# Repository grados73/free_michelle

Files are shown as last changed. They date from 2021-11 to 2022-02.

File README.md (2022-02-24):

# Aquarium controller
>The project, with the working name "free_miechelle", is a response to the lack of market proposals for aquarium control and management devices.

>>Now this project is being developed in another repository. -> https://github.com/grados73/akwa_elektron

## Table of contents
* [General info](#general-info)
* [Screenshots](#screenshots)
* [Technologies](#technologies)
* [HARDWARE](#hardware)
* [Features](#features)
* [Status](#status)
* [Inspiration](#inspiration)
* [Contact](#contact)

## General info
Aquarium hobby has been one of my hobbies for over 10 years, along with cars, sports and electronics. I am a bit of a gadgeteer and like to have everything possible in a smart version, with easy management and monitoring. The same goes for aquariums, I would like to enjoy all the benefits that come with this hobby. Yes, I am a bit lazy. I would like to put in as little effort as possible, while being sure that my fish are well taken care of, even when I am away from home.  But there are no satisfactory solutions on the market to buy and use. All the devices that already exist have either limited capabilities or a technological debt that is heavily visible. Therefore, I decided to make such a device myself. I am currently at the stage of the first prototype, which I assemble using prototype boards. 

## Screenshots
Currently, the device is in a prototype version. It has been assembled on two prototype boards. The next version will have a dedicated PCB.
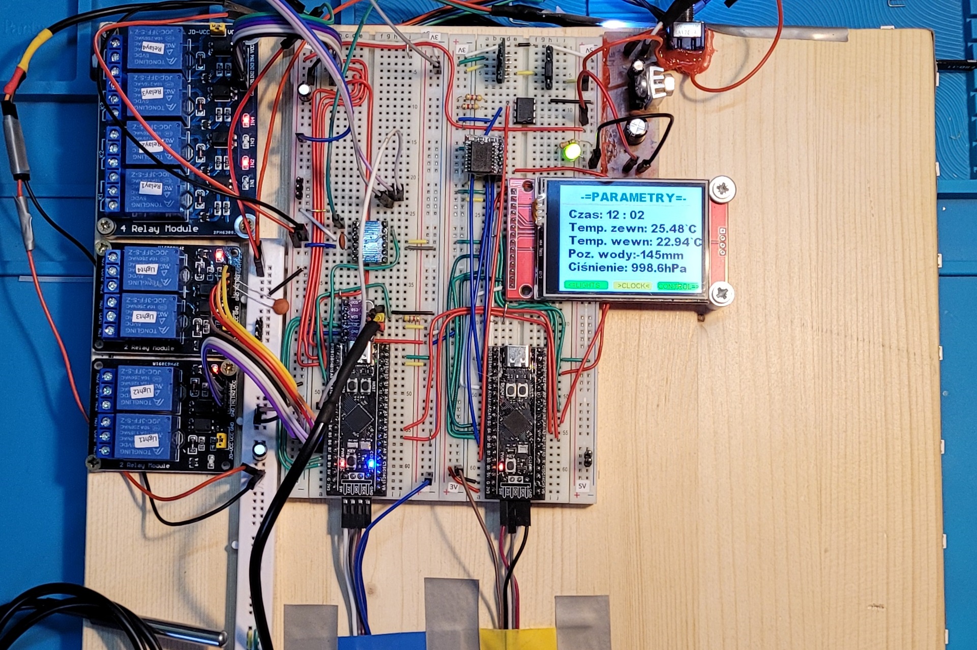
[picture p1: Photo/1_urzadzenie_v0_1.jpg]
Device photo


Short wideo:
https://youtu.be/HiZ6xpy-laI

Currently, the software allows you to control the device and communicate with it through a 2.4" TFT screen, controlled by SPI. All commands are issued via the touch screen available on each of the 8 menu screens. 
Screen photo

## Technologies
Project is created with:
* C,
* HAL for STM32F4,
*
* STM32CubeIDE,
* The Dot Factory v.0.1.4,
* InkScape v.0.92.4,
* Image2Lcd v3.2

## HARDWARE
* 2x Blackpill STM32F411CEU6 
* TFT LCD 2,4″ (240x320px) with ILI9341 controller - SPI
* RTC DS3231 - I2C
* EEPROM memory 1kb - I2C
* BMP280 - I2C
* DS18B20 - 1-WIRE
* Ultrasonic distance sensor - DFRobot SEN0311 - UART
* WS2812b - I2C

## Features
* Menu on TFT Display - DONE
* Touch Interface - DONE
* Relay Control - DONE
* WS2812b LEDs Control  - DONE
* Predefined Activities like feeding or cleaning - DONE
* Display Pressure and Temperature inside and outside the aquarium  - DONE
* Display current day of week, hour and minute and possibility to change them in RTC - DONE
* Measuring the water level in the aquarium - DONE

## To-do list
* Shedules - TODO
* Alarms - TODO
* PCB - TODO
* Watchdog - TODO
* UPS - TODO
* Online access(ESP) - TODO
* Wireless comunitation with sensors - nRF24L01+ - TODO
* Push inormation on telephone - TODO

## Status
Project is in progress and i will develop them to learn ARM and STM32.

## Inspiration
It will be added.

## Contact
Created by https://www.linkedin.com/in/kamil-gradowski-8706991aa - feel free to contact me!
grados73

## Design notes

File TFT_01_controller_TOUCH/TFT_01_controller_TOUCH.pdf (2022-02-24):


12/01/2022

## TFT_01_controller_TOUCH Project Configuration Report

# 1. Description

## 1.1. Project

Project Name | TFT_01_controller_TOUCH
Board Name | custom
Generated with: | STM32CubeMX 6.4.0
Date | 01/12/2022

## 1.2. MCU

MCU Series | STM32F4
MCU Line | STM32F411
MCU name | STM32F411CEUx
MCU Package | UFQFPN48
MCU Pin number | 48

## 1.3. Core(s) information

Core(s) | Arm Cortex-M4

# 2. Pinout Configuration

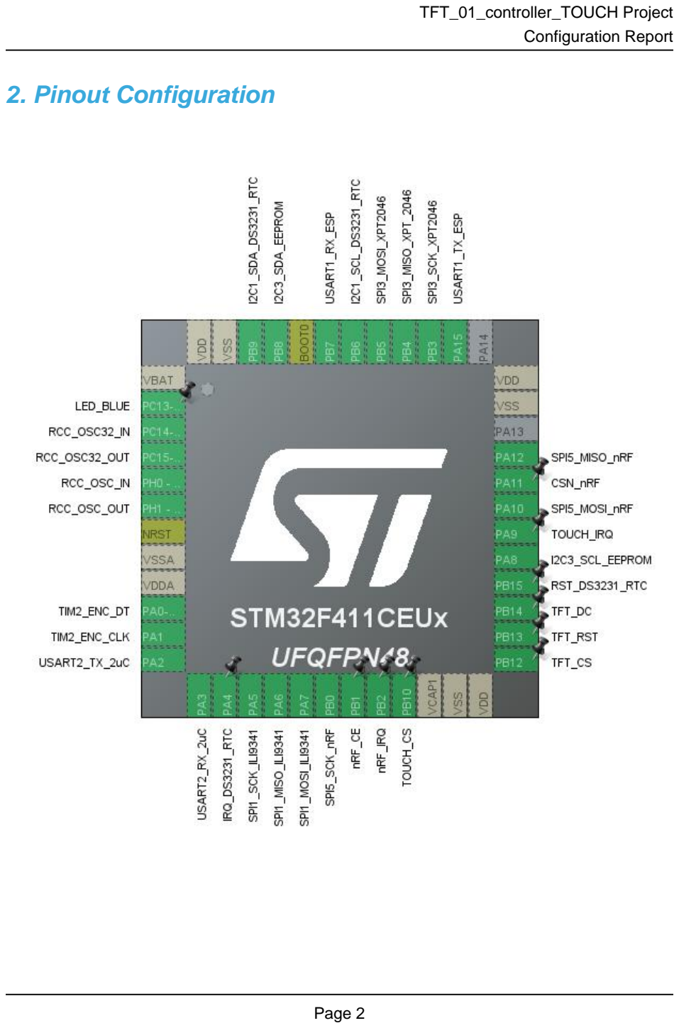
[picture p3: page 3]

# 3. Pins Configuration

Pin Number UFQFPN48 | Pin Name (function after reset) | Pin Type | Alternate Function(s) | Label
1 | VBAT | Power
2 | PC13-ANTI_TAMP * | I/O | GPIO_Output | LED_BLUE
3 | PC14-OSC32_IN | I/O | RCC_OSC32_IN
4 | PC15-OSC32_OUT | I/O | RCC_OSC32_OUT
5 | PH0 - OSC_IN | I/O | RCC_OSC_IN
6 | PH1 - OSC_OUT | I/O | RCC_OSC_OUT
7 | NRST | Reset
8 | VSSA | Power
9 | VDDA | Power
10 | PA0-WKUP | I/O | TIM2_CH1 | TIM2_ENC_DT
11 | PA1 | I/O | TIM2_CH2 | TIM2_ENC_CLK
12 | PA2 | I/O | USART2_TX | USART2_TX_2uC
13 | PA3 | I/O | USART2_RX | USART2_RX_2uC
14 | PA4 | I/O | GPIO_EXTI4 | IRQ_DS3231_RTC
15 | PA5 | I/O | SPI1_SCK | SPI1_SCK_ILI9341
16 | PA6 | I/O | SPI1_MISO | SPI1_MISO_ILI9341
17 | PA7 | I/O | SPI1_MOSI | SPI1_MOSI_ILI9341
18 | PB0 | I/O | SPI5_SCK | SPI5_SCK_nRF
19 | PB1 * | I/O | GPIO_Output | nRF_CE
20 | PB2 | I/O | GPIO_EXTI2 | nRF_IRQ
21 | PB10 * | I/O | GPIO_Output | TOUCH_CS
22 | VCAP1 | Power
23 | VSS | Power
24 | VDD | Power
25 | PB12 * | I/O | GPIO_Output | TFT_CS
26 | PB13 * | I/O | GPIO_Output | TFT_RST
27 | PB14 * | I/O | GPIO_Output | TFT_DC
28 | PB15 * | I/O | GPIO_Input | RST_DS3231_RTC
29 | PA8 | I/O | I2C3_SCL | I2C3_SCL_EEPROM
30 | PA9 | I/O | GPIO_EXTI9 | TOUCH_IRQ
31 | PA10 | I/O | SPI5_MOSI | SPI5_MOSI_nRF
32 | PA11 * | I/O | GPIO_Output | CSN_nRF
33 | PA12 | I/O | SPI5_MISO | SPI5_MISO_nRF
35 | VSS | Power
36 | VDD | Power
38 | PA15 | I/O | USART1_TX | USART1_TX_ESP

Pin Number UFQFPN48 | Pin Name (function after reset) | Pin Type | Alternate Function(s) | Label
39 | PB3 | I/O | SPI3_SCK | SPI3_SCK_XPT2046
40 | PB4 | I/O | SPI3_MISO | SPI3_MISO_XPT_2046
41 | PB5 | I/O | SPI3_MOSI | SPI3_MOSI_XPT2046
42 | PB6 | I/O | I2C1_SCL | I2C1_SCL_DS3231_RTC
43 | PB7 | I/O | USART1_RX | USART1_RX_ESP
44 | BOOT0 | Boot
45 | PB8 | I/O | I2C3_SDA | I2C3_SDA_EEPROM
46 | PB9 | I/O | I2C1_SDA | I2C1_SDA_DS3231_RTC
47 | VSS | Power
48 | VDD | Power

## * The pin is affected with an I/O function

# 4. Clock Tree Configuration

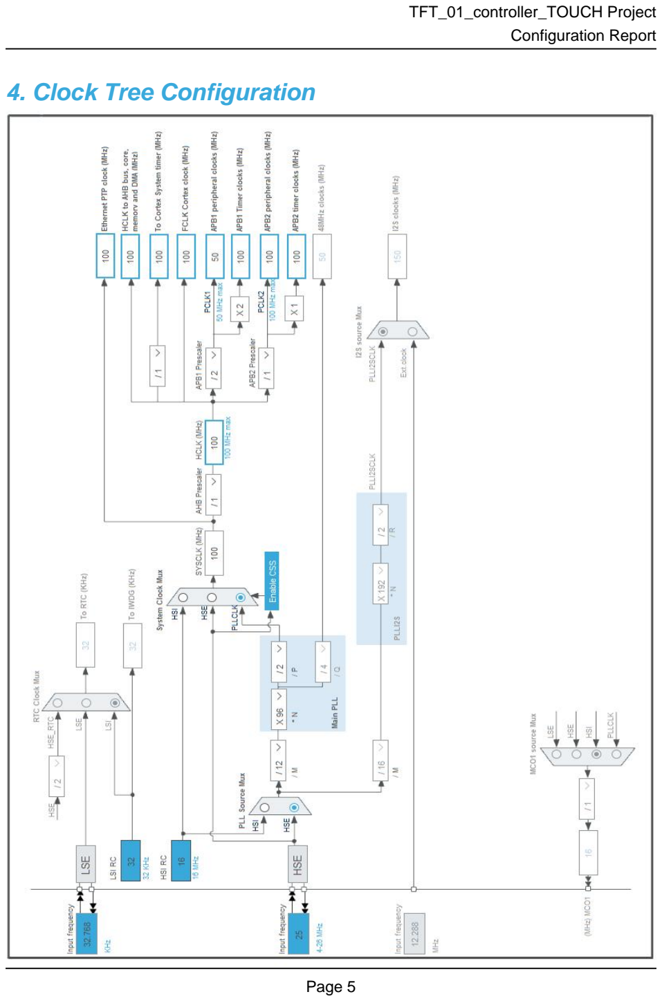
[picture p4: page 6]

# 5. Software Project

## 5.1. Project Settings

Name | Value
Project Name | TFT_01_controller_TOUCH
Project Folder | D:\STM32\free_michelle\TFT_01_controller_TOUCH
Toolchain / IDE | STM32CubeIDE
Firmware Package Name and Version | STM32Cube FW_F4 V1.26.2
Application Structure | Advanced
Generate Under Root | Yes
Do not generate the main() | No
Minimum Heap Size | 0x200
Minimum Stack Size | 0x400

## 5.2. Code Generation Settings

Name | Value
STM32Cube MCU packages and embedded software | Copy only the necessary library files
Generate peripheral initialization as a pair of '.c/.h' files | Yes
Backup previously generated files when re-generating | No
Keep User Code when re-generating | Yes
Delete previously generated files when not re-generated | Yes
Set all free pins as analog (to optimize the power consumption) | No
Enable Full Assert | No

## 5.3. Advanced Settings - Generated Function Calls

Rank | Function Name | Peripheral Instance Name
1 | MX_GPIO_Init | GPIO
2 | SystemClock_Config | RCC
3 | MX_SPI1_Init | SPI1
4 | MX_DMA_Init | DMA
5 | MX_USART2_UART_Init | USART2
6 | MX_SPI3_Init | SPI3
7 | MX_I2C1_Init | I2C1
8 | MX_TIM11_Init | TIM11
9 | MX_TIM10_Init | TIM10
10 | MX_I2C3_Init | I2C3
11 | MX_SPI5_Init | SPI5

Rank | Function Name | Peripheral Instance Name
12 | MX_USART1_UART_Init | USART1
13 | MX_TIM2_Init | TIM2

# 6. Power Consumption Calculator report

## 6.1. Microcontroller Selection

Series | STM32F4
Line | STM32F411
MCU | STM32F411CEUx
Datasheet | DS10314_Rev6

## 6.2. Parameter Selection

Temperature | 25
Vdd | 1.7

## 6.3. Battery Selection

Battery | Li-SOCL2(A3400)
Capacity | 3400.0 mAh
Self Discharge | 0.08 %/month
Nominal Voltage | 3.6 V
Max Cont Current | 100.0 mA
Max Pulse Current | 200.0 mA
Cells in series | 1
Cells in parallel | 1

## 6.4. Sequence

Step | Step1 | Step2
Mode | RUN | STOP
Vdd | 1.7 | 1.7
Voltage Source | Battery | Battery
Range | Scale1-High | No Scale
Fetch Type | SRAM | n/a
CPU Frequency | 100 MHz | 0 Hz
Clock Configuration | HSE PLL | Regulator_LPLV Flash-PwrDwn
Clock Source Frequency | 4 MHz | 0 Hz

### Peripherals

Additional Cons. | 0 mA | 0 mA
Average Current | 12.7 mA | 9 µA
Duration | 0.1 ms | 0.9 ms
DMIPS | 125.0 | 0.0
Ta Max | 104.31 | 105
Category | In DS Table | In DS Table

## 6.5. Results

Sequence Time | 1 ms | Average Current | 1.28 mA
Battery Life | 3 months, 19 days, 6 hours | Average DMIPS | 125.0 DMIPS

## 6.6. Chart

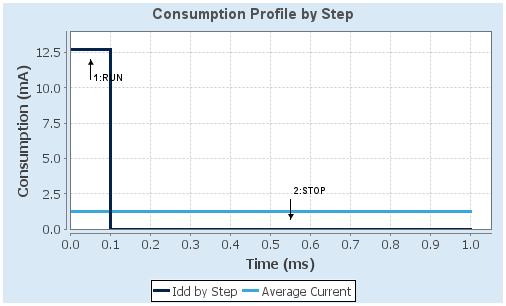
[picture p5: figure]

# 7. Peripherals and Middlewares Configuration

## 7.1. I2C1 I2C: I2C

## 7.1.1. Parameter Settings:

### Master Features:

I2C Speed Mode | Fast Mode *
I2C Clock Speed (Hz) | 400000
Fast Mode Duty Cycle | Duty cycle Tlow/Thigh = 2

### Slave Features:

Clock No Stretch Mode | Disabled
Primary Address Length selection | 7-bit
Dual Address Acknowledged | Disabled
Primary slave address | 0
General Call address detection | Disabled

## 7.2. I2C3 I2C: I2C

## 7.2.1. Parameter Settings:

### Master Features:

I2C Speed Mode | Standard Mode
I2C Clock Speed (Hz) | 100000

### Slave Features:

Clock No Stretch Mode | Disabled
Primary Address Length selection | 7-bit
Dual Address Acknowledged | Disabled
Primary slave address | 0
General Call address detection | Disabled

## 7.3. RCC High Speed Clock (HSE): Crystal/Ceramic Resonator Low Speed Clock (LSE) : Crystal/Ceramic Resonator

## 7.3.1. Parameter Settings:

### System Parameters:

VDD voltage (V) | 3.3
Instruction Cache | Enabled
Prefetch Buffer | Enabled
Data Cache | Enabled
Flash Latency(WS) | 3 WS (4 CPU cycle)

### RCC Parameters:

HSI Calibration Value | 16
TIM Prescaler Selection | Disabled
HSE Startup Timout Value (ms) | 100
LSE Startup Timout Value (ms) | 5000

### Power Parameters:

Power Regulator Voltage Scale | Power Regulator Voltage Scale 1

## 7.4. SPI1 Mode: Full-Duplex Master

## 7.4.1. Parameter Settings:

### Basic Parameters:

Frame Format | Motorola
Data Size | 8 Bits
First Bit | MSB First

### Clock Parameters:

Prescaler (for Baud Rate) | 8 *
Baud Rate | 12.5 MBits/s *
Clock Polarity (CPOL) | Low
Clock Phase (CPHA) | 1 Edge

### Advanced Parameters:

CRC Calculation | Disabled
NSS Signal Type | Software

## 7.5. SPI3 Mode: Full-Duplex Master

## 7.5.1. Parameter Settings:

### Basic Parameters:

Frame Format | Motorola
Data Size | 8 Bits

First Bit | MSB First

### Clock Parameters:

Prescaler (for Baud Rate) | 32 *
Baud Rate | 1.5625 MBits/s *
Clock Polarity (CPOL) | Low
Clock Phase (CPHA) | 1 Edge

### Advanced Parameters:

CRC Calculation | Disabled
NSS Signal Type | Software

## 7.6. SPI5 Mode: Full-Duplex Master

## 7.6.1. Parameter Settings:

### Basic Parameters:

Frame Format | Motorola
Data Size | 8 Bits
First Bit | MSB First

### Clock Parameters:

Prescaler (for Baud Rate) | 2
Baud Rate | 50.0 MBits/s *
Clock Polarity (CPOL) | Low
Clock Phase (CPHA) | 1 Edge

### Advanced Parameters:

CRC Calculation | Disabled
NSS Signal Type | Software

## 7.7. SYS Timebase Source: SysTick

## 7.8. TIM2 Combined Channels: Encoder Mode

## 7.8.1. Parameter Settings:

### Counter Settings:

Prescaler (PSC - 16 bits value) | 0

Counter Mode | Up
Counter Period (AutoReload Register - 32 bits value ) | 4294967295
Internal Clock Division (CKD) | No Division
auto-reload preload | Disable

### Trigger Output (TRGO) Parameters:

Master/Slave Mode (MSM bit) | Disable (Trigger input effect not delayed)
Trigger Event Selection | Reset (UG bit from TIMx_EGR)

### Encoder:

Encoder Mode | Encoder Mode TI1
____ Parameters for Channel 1 ____
Polarity | Rising Edge
IC Selection | Direct
Prescaler Division Ratio | No division
Input Filter | 0
____ Parameters for Channel 2 ____
Polarity | Rising Edge
IC Selection | Direct
Prescaler Division Ratio | No division
Input Filter | 0

## 7.9. TIM10 mode: Activated

## 7.9.1. Parameter Settings:

### Counter Settings:

Prescaler (PSC - 16 bits value) | 9999 *
Counter Mode | Up
Counter Period (AutoReload Register - 16 bits value ) | 9999 *
Internal Clock Division (CKD) | No Division
auto-reload preload | Disable

## 7.10. TIM11 mode: Activated

## 7.10.1. Parameter Settings:

### Counter Settings:

Prescaler (PSC - 16 bits value) | 14999 *

Counter Mode | Up
Counter Period (AutoReload Register - 16 bits value ) | 29999 *
Internal Clock Division (CKD) | Division by 4 *
auto-reload preload | Disable

## 7.11. USART1 Mode: Asynchronous

## 7.11.1. Parameter Settings:

### Basic Parameters:

Baud Rate | 115200
Word Length | 8 Bits (including Parity)
Parity | None
Stop Bits | 1

### Advanced Parameters:

Data Direction | Receive and Transmit
Over Sampling | 16 Samples

## 7.12. USART2 Mode: Asynchronous

## 7.12.1. Parameter Settings:

### Basic Parameters:

Baud Rate | 115200
Word Length | 8 Bits (including Parity)
Parity | None
Stop Bits | 1

### Advanced Parameters:

Data Direction | Receive and Transmit
Over Sampling | 16 Samples

### * User modified value

# 8. System Configuration

## 8.1. GPIO configuration

IP | Pin | Signal | GPIO mode | GPIO pull/up pull down | Max Speed | User Label
I2C1 | PB6 | I2C1_SCL | Alternate Function Open Drain | No pull-up and no pull-down | Very High * | I2C1_SCL_DS3231_RTC
| PB9 | I2C1_SDA | Alternate Function Open Drain | No pull-up and no pull-down | Very High * | I2C1_SDA_DS3231_RTC
I2C3 | PA8 | I2C3_SCL | Alternate Function Open Drain | No pull-up and no pull-down | Very High * | I2C3_SCL_EEPROM
| PB8 | I2C3_SDA | Alternate Function Open Drain | No pull-up and no pull-down | Very High * | I2C3_SDA_EEPROM
RCC | PC14-OSC32_IN | RCC_OSC32_IN | n/a | n/a | n/a
| PC15-OSC32_OU T | RCC_OSC32_O UT | n/a | n/a | n/a
| PH0 -OSC_IN | RCC_OSC_IN | n/a | n/a | n/a
| PH1 -OSC_OUT | RCC_OSC_OUT | n/a | n/a | n/a
SPI1 | PA5 | SPI1_SCK | Alternate Function Push Pull | No pull-up and no pull-down | Very High * | SPI1_SCK_ILI9341
| PA6 | SPI1_MISO | Alternate Function Push Pull | No pull-up and no pull-down | Very High * | SPI1_MISO_ILI9341
| PA7 | SPI1_MOSI | Alternate Function Push Pull | No pull-up and no pull-down | Very High * | SPI1_MOSI_ILI9341
SPI3 | PB3 | SPI3_SCK | Alternate Function Push Pull | No pull-up and no pull-down | Very High * | SPI3_SCK_XPT2046
| PB4 | SPI3_MISO | Alternate Function Push Pull | No pull-up and no pull-down | Very High * | SPI3_MISO_XPT_2046
| PB5 | SPI3_MOSI | Alternate Function Push Pull | No pull-up and no pull-down | Very High * | SPI3_MOSI_XPT2046
SPI5 | PB0 | SPI5_SCK | Alternate Function Push Pull | No pull-up and no pull-down | Very High * | SPI5_SCK_nRF
| PA10 | SPI5_MOSI | Alternate Function Push Pull | No pull-up and no pull-down | Very High * | SPI5_MOSI_nRF
| PA12 | SPI5_MISO | Alternate Function Push Pull | No pull-up and no pull-down | Very High * | SPI5_MISO_nRF

IP | Pin | Signal | GPIO mode | GPIO pull/up pull down | Max Speed | User Label
TIM2 | PA0-WKUP | TIM2_CH1 | Alternate Function Push Pull | No pull-up and no pull-down | Low | TIM2_ENC_DT
| PA1 | TIM2_CH2 | Alternate Function Push Pull | No pull-up and no pull-down | Low | TIM2_ENC_CLK
USART1 | PA15 | USART1_TX | Alternate Function Push Pull | No pull-up and no pull-down | Very High * | USART1_TX_ESP
| PB7 | USART1_RX | Alternate Function Push Pull | No pull-up and no pull-down | Very High * | USART1_RX_ESP
USART2 | PA2 | USART2_TX | Alternate Function Push Pull | No pull-up and no pull-down | Very High * | USART2_TX_2uC
| PA3 | USART2_RX | Alternate Function Push Pull | No pull-up and no pull-down | Very High * | USART2_RX_2uC
| ANTI_TAMP | GPIO_Output | Output Push Pull | No pull-up and no pull-down | Low | LED_BLUE
| PA4 | GPIO_EXTI4 | External Interrupt Mode with Falling edge trigger detection | Pull-up * | n/a | IRQ_DS3231_RTC
| PB1 | GPIO_Output | Output Push Pull | No pull-up and no pull-down | Low | nRF_CE
| PB2 | GPIO_EXTI2 | External Interrupt Mode with Rising edge trigger detection | No pull-up and no pull-down | n/a | nRF_IRQ
| PB10 | GPIO_Output | Output Push Pull | No pull-up and no pull-down | Low | TOUCH_CS
| PB12 | GPIO_Output | Output Push Pull | No pull-up and no pull-down | Low | TFT_CS
| PB13 | GPIO_Output | Output Push Pull | No pull-up and no pull-down | Low | TFT_RST
| PB14 | GPIO_Output | Output Push Pull | No pull-up and no pull-down | Low | TFT_DC
| PB15 | GPIO_Input | Input mode | No pull-up and no pull-down | n/a | RST_DS3231_RTC
| PA9 | GPIO_EXTI9 | External Interrupt Mode with Falling edge trigger detection | No pull-up and no pull-down | n/a | TOUCH_IRQ
| PA11 | GPIO_Output | Output Push Pull | No pull-up and no pull-down | Low | CSN_nRF
GPIO | PC13-

## 8.2. DMA configuration

DMA request | Stream | Direction | Priority
USART2_RX | DMA1_Stream5 | Peripheral To Memory | Low
USART2_TX | DMA1_Stream6 | Memory To Peripheral | Low
I2C1_RX | DMA1_Stream0 | Peripheral To Memory | Low
I2C1_TX | DMA1_Stream1 | Memory To Peripheral | Low

## USART2_RX: DMA1_Stream5 DMA request Settings:

Mode: | Normal
Use fifo: | Disable
Peripheral Increment: | Disable
Memory Increment: | Enable *
Peripheral Data Width: | Byte
Memory Data Width: | Byte

## USART2_TX: DMA1_Stream6 DMA request Settings:

Mode: | Normal
Use fifo: | Disable
Peripheral Increment: | Disable
Memory Increment: | Enable *
Peripheral Data Width: | Byte
Memory Data Width: | Byte

## I2C1_RX: DMA1_Stream0 DMA request Settings:

Mode: | Normal
Use fifo: | Disable
Peripheral Increment: | Disable
Memory Increment: | Enable *
Peripheral Data Width: | Byte
Memory Data Width: | Byte

## I2C1_TX: DMA1_Stream1 DMA request Settings:

Mode: | Normal
Use fifo: | Disable

Peripheral Increment: | Disable
Memory Increment: | Enable *
Peripheral Data Width: | Byte
Memory Data Width: | Byte

## 8.3. NVIC configuration

## 8.3.1. NVIC

Interrupt Table | Enable | Preenmption Priority | SubPriority
Non maskable interrupt | true | 0 | 0
Hard fault interrupt | true | 0 | 0
Memory management fault | true | 0 | 0
Pre-fetch fault, memory access fault | true | 0 | 0
Undefined instruction or illegal state | true | 0 | 0
System service call via SWI instruction | true | 0 | 0
Debug monitor | true | 0 | 0
Pendable request for system service | true | 0 | 0
System tick timer | true | 0 | 0
EXTI line4 interrupt | true | 0 | 0
DMA1 stream0 global interrupt | true | 0 | 0
DMA1 stream1 global interrupt | true | 0 | 0
DMA1 stream5 global interrupt | true | 0 | 0
DMA1 stream6 global interrupt | true | 0 | 0
TIM1 update interrupt and TIM10 global interrupt | true | 0 | 0
TIM1 trigger and commutation interrupts and TIM11 global interrupt | true | 0 | 0
I2C1 event interrupt | true | 0 | 0
I2C1 error interrupt | true | 0 | 0
USART2 global interrupt | true | 0 | 0
SPI3 global interrupt | true | 0 | 0
PVD interrupt through EXTI line 16 | | unused
Flash global interrupt | | unused
RCC global interrupt | | unused
EXTI line2 interrupt | | unused
EXTI line[9:5] interrupts | | unused
TIM2 global interrupt | | unused
SPI1 global interrupt | | unused
USART1 global interrupt | | unused
I2C3 event interrupt | | unused
I2C3 error interrupt | | unused
FPU global interrupt | | unused
SPI5 global interrupt | | unused

## 8.3.2. NVIC Code generation

Enabled interrupt Table | Select for init | Generate IRQ | Call HAL handler

Enabled interrupt Table | Select for init sequence ordering | Generate IRQ handler | Call HAL handler
Non maskable interrupt | false | true | false
Hard fault interrupt | false | true | false
Memory management fault | false | true | false
Pre-fetch fault, memory access fault | false | true | false
Undefined instruction or illegal state | false | true | false
System service call via SWI instruction | false | true | false
Debug monitor | false | true | false
Pendable request for system service | false | true | false
System tick timer | false | true | true
EXTI line4 interrupt | true | true | true
DMA1 stream0 global interrupt | false | true | true
DMA1 stream1 global interrupt | false | true | true
DMA1 stream5 global interrupt | false | true | true
DMA1 stream6 global interrupt | false | true | true
TIM1 update interrupt and TIM10 global interrupt | false | true | true
TIM1 trigger and commutation interrupts and TIM11 global interrupt | false | true | true
I2C1 event interrupt | true | true | true
I2C1 error interrupt | false | true | true
USART2 global interrupt | true | true | true
SPI3 global interrupt | true | true | true

### * User modified value

# 9. System Views

## 9.1. Category view 9.1.1. Current

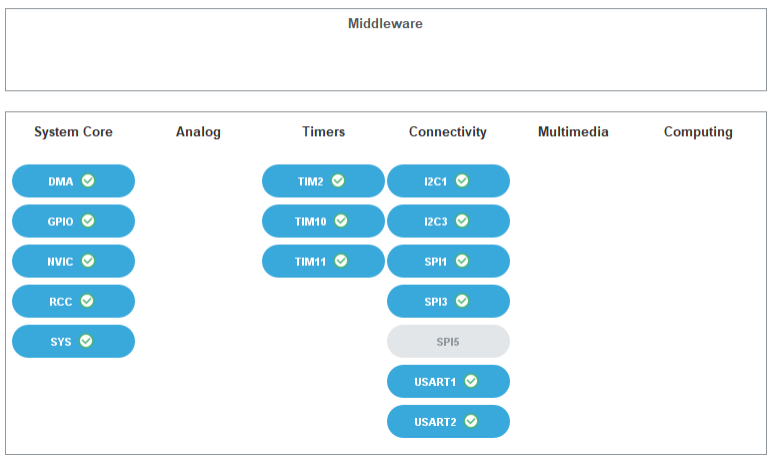
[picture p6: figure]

# 10. Docs & Resources

Type | Link
Datasheet | http://www.st.com/resource/en/datasheet/DM00115249.pdf
Reference manual | http://www.st.com/resource/en/reference_manual/DM00119316.pdf
Programming manual | http://www.st.com/resource/en/programming_manual/DM00046982.pdf
Errata sheet | http://www.st.com/resource/en/errata_sheet/DM00137034.pdf
Application note | http://www.st.com/resource/en/application_note/CD00167594.pdf
Application note | http://www.st.com/resource/en/application_note/CD00211314.pdf
Application note | http://www.st.com/resource/en/application_note/CD00249778.pdf
Application note | http://www.st.com/resource/en/application_note/CD00259245.pdf
Application note | http://www.st.com/resource/en/application_note/CD00264321.pdf
Application note | http://www.st.com/resource/en/application_note/CD00264342.pdf
Application note | http://www.st.com/resource/en/application_note/CD00264379.pdf
Application note | http://www.st.com/resource/en/application_note/DM00024853.pdf
Application note | http://www.st.com/resource/en/application_note/DM00040802.pdf
Application note | http://www.st.com/resource/en/application_note/DM00040808.pdf
Application note | http://www.st.com/resource/en/application_note/DM00042534.pdf
Application note | http://www.st.com/resource/en/application_note/DM00046011.pdf
Application note | http://www.st.com/resource/en/application_note/DM00072315.pdf
Application note | http://www.st.com/resource/en/application_note/DM00073742.pdf
Application note | http://www.st.com/resource/en/application_note/DM00073853.pdf
Application note | http://www.st.com/resource/en/application_note/DM00080497.pdf
Application note | http://www.st.com/resource/en/application_note/DM00081379.pdf
Application note | http://www.st.com/resource/en/application_note/DM00115714.pdf
Application note | http://www.st.com/resource/en/application_note/DM00129215.pdf
Application note | http://www.st.com/resource/en/application_note/DM00144612.pdf
Application note | http://www.st.com/resource/en/application_note/DM00156364.pdf

Application note | http://www.st.com/resource/en/application_note/DM00160482.pdf
Application note | http://www.st.com/resource/en/application_note/DM00213525.pdf
Application note | http://www.st.com/resource/en/application_note/DM00220769.pdf
Application note | http://www.st.com/resource/en/application_note/DM00226326.pdf
Application note | http://www.st.com/resource/en/application_note/DM00236305.pdf
Application note | http://www.st.com/resource/en/application_note/DM00257177.pdf
Application note | http://www.st.com/resource/en/application_note/DM00272912.pdf
Application note | http://www.st.com/resource/en/application_note/DM00281138.pdf
Application note | http://www.st.com/resource/en/application_note/DM00296349.pdf
Application note | http://www.st.com/resource/en/application_note/DM00315319.pdf
Application note | http://www.st.com/resource/en/application_note/DM00325582.pdf
Application note | http://www.st.com/resource/en/application_note/DM00327191.pdf
Application note | http://www.st.com/resource/en/application_note/DM00354244.pdf
Application note | http://www.st.com/resource/en/application_note/DM00380469.pdf
Application note | http://www.st.com/resource/en/application_note/DM00395696.pdf
Application note | http://www.st.com/resource/en/application_note/DM00431633.pdf
Application note | http://www.st.com/resource/en/application_note/DM00493651.pdf
Application note | http://www.st.com/resource/en/application_note/DM00536349.pdf
Application note | http://www.st.com/resource/en/application_note/DM00725181.pdf

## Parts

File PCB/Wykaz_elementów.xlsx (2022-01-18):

Nazwa | Ilość | Link | Cena | Suma
STM32F411 BlackPill | 2 | ALI (https://pl.aliexpress.com/item/1005001456186625.html) | 30 | 60
Wyświetlacz dotykowy TFT LCD 2,4″ 240x320px | 1 | SALOMON (https://sklep.msalamon.pl/produkt/tft-24-spi-dotyk/) | 56 | 56
RTC DS3231M | 1 | ALLEGRO (https://allegrolokalnie.pl/oferta/modul-czasu-rzeczywistego-rtc-ds3231) | 10 | 10
EEPROM 24AA01-I/P | 1 | BOTLAND (https://botland.com.pl/pamieci-eeprom/4588-pamiec-eeprom-1kb-i2c-24aa01-i-p-5904422303020.html) | 2 | 2
Enkoder | 1 | BOTLAND (https://botland.com.pl/enkodery/6905-enkoder-12-impulsow-20mm-ec12-pionowy-5904422335250.html) | 3.5 | 3.5
ESP8266_NodeMCU_v2 | 1 | ALI (https://pl.aliexpress.com/item/4000160133215.html) | 15 | 15
Nrf240l | 1 | BOTLAND (https://botland.com.pl/moduly-radiowe/1687-modul-radiowy-nrf24l01-24ghz-transceiver-tht-czarny-5903351242721.html) | 8 | 8
BMP280 | 1 | BOTLAND (https://botland.com.pl/czujniki-cisnienia/7245-bmp280-cyfrowy-barometr-czujnik-cisnienia-110kpa-i2cspi-33v-5904422310042.html) | 20 | 20
DS18B20 | 1 | BOTLAND (https://botland.com.pl/sondy-wodoodporne/16554-sonda-wodoodporna-z-czujnikiem-temperatury-ds18b20-okystar-1m.html) | 13 | 13
Buzzer | 1 | BOTLAND (https://botland.com.pl/buzzery-generatory-dzwieku/2609-buzzer-bez-generatora-3-16v-14mm-tht-5904422366407.html) | 2.2 | 2.2
Przekaźnik FINDER 36.11 | 8 | TME (https://www.tme.eu/pl/details/36.11.9.003.4011/przekazniki-elektromagn-miniaturowe/finder/) | 10.5 | 84
Konwerter stanów BSS138 | 1 | TME (https://www.tme.eu/pl/details/bss138-yan/tranzystory-z-kanalem-n-smd/yangjie-technology/bss138/) | 0.2 | 0.2
Stabilizator 3,3V LD11177V33 | 2 | TME (https://www.tme.eu/pl/details/ld1117av33/stabilizatory-napiecia-nieregulowane-ldo/stmicroelectronics/) | 1.8 | 3.6
TackSwitch | 2 | ALLEGRO (https://allegro.pl/oferta/bs800l-mikroprzelacznik-tact-dpdt-0-1a-30vdc-e6708-8479810064) | 2.5 | 5
Koszyk na baterie | 1 | BOTLAND (https://botland.com.pl/koszyki-na-baterie/10158-podstawka-na-baterie-typu-cr2032-3v-z-blokada-5904422303600.html) | 1 | 1
Rezystor 10k 1206 | 3 | TME (https://www.tme.eu/pl/details/hp06-10k5%25/rezystory-smd-1206/royal-ohm/hp06w2j0103t5e/) | 0.25 | 0.75
Rezystor 4k7 1206 | 7 | TME (https://www.tme.eu/pl/details/hp06-4k75%25/rezystory-smd-1206/royal-ohm/hp06w2j0472t5e/) | 0.25 | 1.75
Rezystor 2k2 1206 | 8 | TME (https://www.tme.eu/pl/details/hp06-2k25%25/rezystory-smd-1206/royal-ohm/hp06w2j0222t5e/) | 0.25 | 2
Rezystor THT 110, 730, 290 | 3 | TME (https://www.tme.eu/pl/details/1_4w110r/rezystory-weglowe-tht-1-4w/royal-ohm/cfr0w4j0111a50/) | 0.08 | 0.24
Kondensator SMD 100nF 1206 | 7 | TME (https://www.tme.eu/pl/details/sh31b104k101ct/kondensatory-mlcc-smd-1206/walsin/) | 0.3 | 2.1
Kondensator THT Elektrolit 47uF | 3 | TME (https://www.tme.eu/pl/details/ce-47_50pht-y/kondensatory-elektrolityczne-tht-105degc/aishi/ewh1hm470e11ot/) | 0.25 | 0.75
Kondensator SMD 1uF 1206 | 1 | TME (https://www.tme.eu/pl/details/cm-1u-y5v/kondensatory-mlcc-tht/sr-passives/) | 0.4 | 0.4
Stabilizator 5V L7805 | 1 | TME (https://www.tme.eu/pl/details/l7805abv/stabilizatory-napiecia-nieregulowane/stmicroelectronics/) | 1.5 | 1.5
Złącze GROVE 1x4 2.00mm | 4 | BOTLAND (https://botland.com.pl/grove-przewody-polaczeniowe/15452-grove-uniwersalne-zlacze-katowe-90-4-pin-10szt-5904422323721.html) | 0.35 | 1.4
PinHead 1x02 2,54 | 3 |  | 0.02 | 0.06
Złącze ARK 1x03 | 1 | BOTLAND (https://botland.com.pl/zlacza-ark/9444-zlacze-ark-raster-254mm-3-pin-10szt.html) | 1.5 | 1.5
BSS138 | 1 | TME (https://www.tme.eu/pl/details/bss138-tp/tranzystory-z-kanalem-n-smd/micro-commercial-components/) | 0.26 | 0.26
MMBT4403_PNP | 8 | TME (https://www.tme.eu/pl/details/mmbt4403-dio/tranzystory-pnp-smd/diotec-semiconductor/mmbt4403/) | 0.25 | 2
Złącze ARK 1x03 5mm | 8 | BOTLAND (https://botland.com.pl/zlacza-ark/808-zlacze-ark-kf301-raster-50mm-3-pin-5szt-5904422353339.html) | 1.1 | 8.8
Złącze ARK 1,02 5mm | 1 | BOTLAND (https://botland.com.pl/zlacza-ark/810-zlacze-ark-kf301-raster-50mm-2-pin-10-szt-5904422329693.html) | 0.7 | 0.7
Dioda prostownicza 1N4148 | 8 | BOTLAND (https://botland.com.pl/diody-prostownicze/4927-dioda-prostownicza-1n4148-100v-015a-10szt-5903351244442.html) | 0.09 | 0.72
Podstawka na EEPROM | 1 | BOTLAND (https://botland.com.pl/podstawki-pod-uklady-scalone/92-podstawka-do-ukladow-dip-8-pin-zwykla-5-szt.html) | 0.2 | 0.2
Gniazdo żeńskie 2x4 | 1 | BOTLAND (https://botland.com.pl/gniazda-szpilkowe-goldpin/3425-gniazdo-zenskie-2x4-raster-254mm-10-szt.html) | 0.22 | 0.22
Gniazdo Goldpin proste | 8 | BOTLAND (https://botland.com.pl/gniazda-szpilkowe-goldpin/8505-gniazdo-proste-1x20pin-raster-254mm-pionowe-5904422311780.html) | 0.5 | 4
Gniazdo DC IN 5,5X2,5 | 1 | BOTLAND (https://botland.com.pl/przewody-i-zlacza-zasilajace/412-gniazdo-dc-55-x-25mm-do-druku-poziome-5904422329471.html) | 0.4 | 0.4
 |  |  |  | 313.25

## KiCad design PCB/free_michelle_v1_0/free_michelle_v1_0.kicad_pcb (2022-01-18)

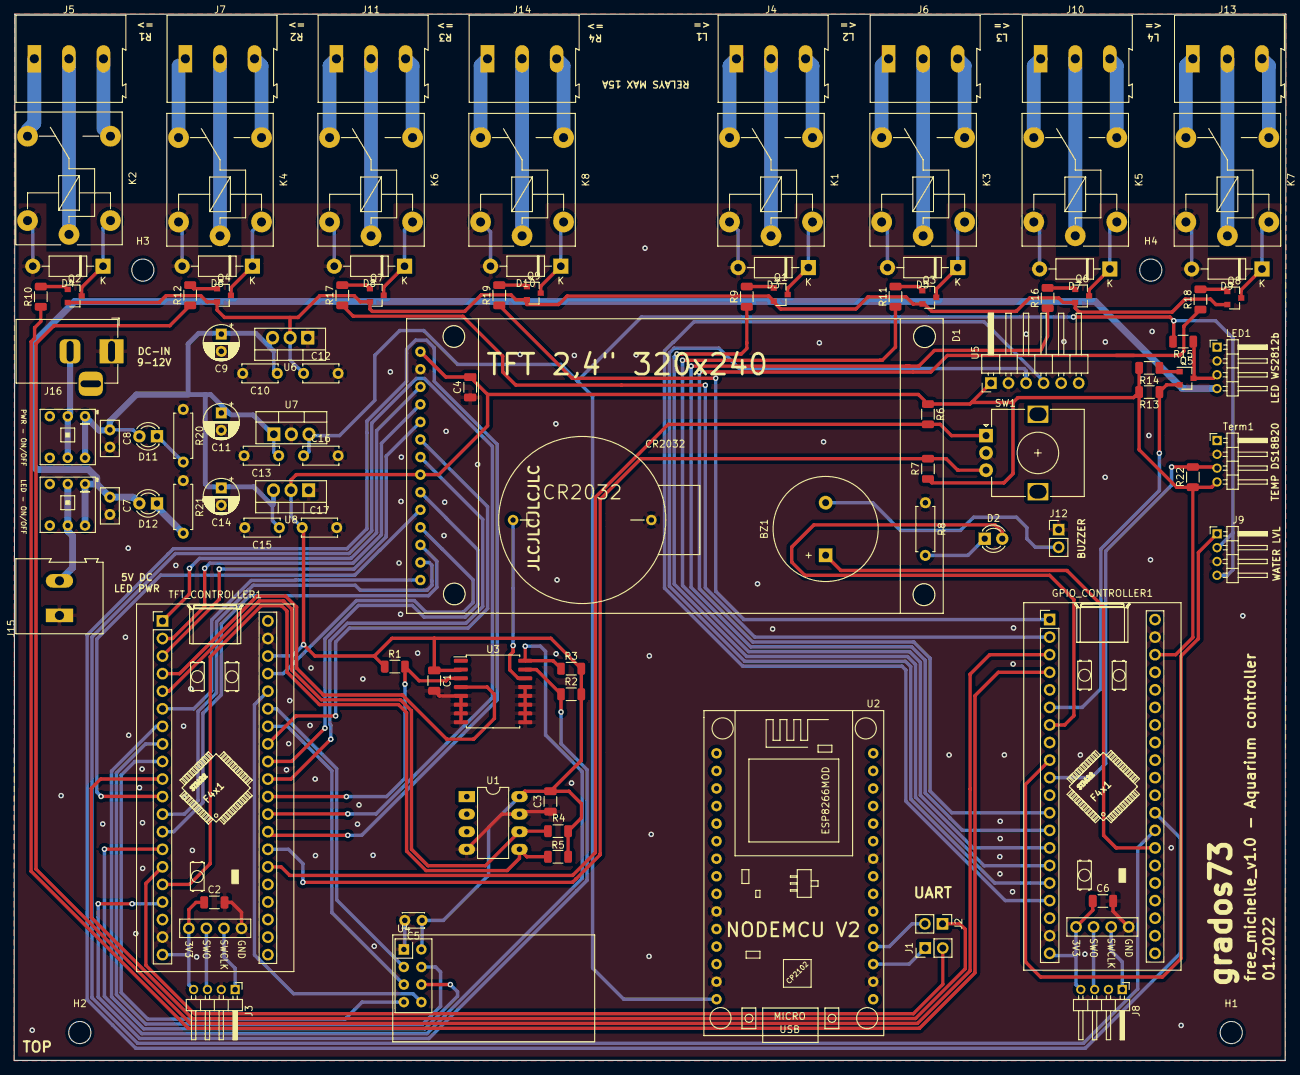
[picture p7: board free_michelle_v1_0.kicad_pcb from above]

Board: 2 copper layers, 183.9 x 151.3 mm, 105 parts (0 on the bottom side), 105 nets.

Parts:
BZ1: Buzzer; Buzzer_15x7.5RM7.6
C1, C2, C3, C4, C6: 100nF; C_1206_3216Metric
C5: 1uF; C_Disc_D3.0mm_W2.0mm_P2.50mm
C7, C8: 100nF; C_Disc_D5.0mm_W2.5mm_P2.50mm
C9, C11, C14: 47uF; CP_Radial_D5.0mm_P2.50mm
C10, C12, C13, C15, C16, C17: 100nF; C_Disc_D5.0mm_W2.5mm_P5.00mm
CR2032: 3V; CR2032_KOSZYK
D1: TFT_320x240_ILI9341; TFT_2_4_c_240x320_SPI
D2: GREEN_USER_LED; LED_D3.0mm_IRGrey
D3, D4, D5, D6, D7, D8, D9, D10: 1N4148; D_DO-41_SOD81_P10.16mm_Horizontal
D11: RED_LED; LED_D3.0mm
D12: YELLOW_LED; LED_D3.0mm_Clear
GPIO_CONTROLLER1: BlackPill_STM32F4x1_grados73; grados73_BlackPill_STM32F4x1
H1, H2, H3, H4: MountingHole; MountingHole_3.2mm_M3
J1: Zworka_TX; PinHeader_1x02_P2.54mm_Vertical
J2: Zworka_RX; PinHeader_1x02_P2.54mm_Vertical
J3, J8: GROVE_SW; PinHeader_1x04_P2.00mm_Horizontal
J4, J5, J6, J7, J10, J11, J13, J14: ARK; TerminalBlock_Altech_AK300-3_P5.00mm
J9: A02YYUW_GroveCON; PinHeader_1x04_P2.00mm_Horizontal
J12: Zworka_Buzzer; PinHeader_1x02_P2.54mm_Vertical
J15: Gniazdo 5VP DC 5,5x2,5; TerminalBlock_Altech_AK300-2_P5.00mm
J16: Gniazdo 9V DC 5,5x2,5; BarrelJack_Horizontal
K1, K2, K3, K4, K5, K6, K7, K8: FINDER-36.11; Relay_SPDT_Finder_36.11
LED1: WS2812b_GROVE; PinHeader_1x04_P2.00mm_Horizontal
Q1, Q2, Q3, Q4, Q6, Q7, Q8, Q9: MMBT4403_PNP; SOT-23
Q5: BSS138; SOT-23
R1, R6, R7: 10k; R_1206_3216Metric
R2, R3, R13, R14, R15: 4k7; R_1206_3216Metric
R4, R5, R22: 4K7; R_1206_3216Metric
R8: 110; R_Axial_DIN0207_L6.3mm_D2.5mm_P7.62mm_Horizontal
R9, R10, R11, R12, R16, R17, R18, R19: 2.2k; R_1206_3216Metric
R20: 730; R_Axial_DIN0207_L6.3mm_D2.5mm_P7.62mm_Horizontal
R21: 290; R_Axial_DIN0207_L6.3mm_D2.5mm_P7.62mm_Horizontal
SW1: Rotary_Encoder; RotaryEncoder_Alps_EC12E_Vertical_H20mm
SW2, SW3: SW_Push; Switch_BS800L
TFT_CONTROLLER1: BlackPill_STM32F4x1_grados73; grados73_BlackPill_STM32F4x1
Term1: DS18B20_GroveCON; PinHeader_1x04_P2.00mm_Horizontal
U1: EEPROM_24AA01; DIP-8_W7.62mm_LongPads
U2: ESP8266_NodeMCU_v2; NodeMCU_v2_ESP_grados73
U3: DS3231M_RTC; SOIC-16W_7.5x10.3mm_P1.27mm
U4: NRF24L01_Breakout; nRF24L01_Breakout
U5: BMP280; PinHeader_1x06_P2.54mm_Horizontal
U6, U8: LD1117AV33; TO-220-3_Vertical
U7: L7805; TO-220-3_Vertical

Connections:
+3.3VP: C12.1, Q1.2, Q2.2, Q3.2, Q4.2, Q6.2, Q7.2, Q8.2, Q9.2, U6.2
+3V3: C1.1, C2.1, C3.2, C4.2, C5.1, C6.1, C17.1, D1.1, D1.8, GPIO_CONTROLLER1.18, GPIO_CONTROLLER1.40, GPIO_CONTROLLER1.44, J3.4, J8.4, R1.1, R2.2, R3.2, R4.1, R5.1, R6.1, R7.1, R13.2, R14.2, R22.1, TFT_CONTROLLER1.18, TFT_CONTROLLER1.40, TFT_CONTROLLER1.44, Term1.4, U1.8, U3.2, U4.2, U5.1, U8.2
+5V: C16.1, J9.2, J9.4, R15.2, U2.15, U7.3
+5VP: C7.1, D12.2, LED1.4, SW3.1
+9V: C8.1, C9.1, C10.1, C11.1, C13.1, C14.1, C15.1, D11.2, SW2.1, U6.3, U7.1, U8.3
A02YYUW_U6_RX_PA12: GPIO_CONTROLLER1.29, J9.1
BMP_SCL_PB8: GPIO_CONTROLLER1.36, U5.3
BMP_SDA_PB9: GPIO_CONTROLLER1.37, U5.4
Buzzer_PA1: BZ1.1, GPIO_CONTROLLER1.7
DS18B20_1WIRE_PA15: GPIO_CONTROLLER1.30, R22.2, Term1.3
DS3231_IRQ_PA4: R1.2, TFT_CONTROLLER1.10, U3.3
DS3231_RST_PB15: TFT_CONTROLLER1.24, U3.4
DS3231_SCL_PB6: R3.1, TFT_CONTROLLER1.34, U3.16
DS3231_SDA_PB9: R2.1, TFT_CONTROLLER1.37, U3.15
EEPROM_SCL_PA8: R4.2, TFT_CONTROLLER1.25, U1.6
EEPROM_SDA_PB8: R5.2, TFT_CONTROLLER1.36, U1.5
ENC_CLK_PA1: R7.2, SW1.B, TFT_CONTROLLER1.7
ENC_DT_PA0: R6.2, SW1.A, TFT_CONTROLLER1.6
ESP_RX_TX_STM__U1_PA15: J2.1, TFT_CONTROLLER1.30
ESP_TX_RX_STM__U1_PB7: J1.2, TFT_CONTROLLER1.35
GND: C1.2, C2.2, C3.1, C4.1, C5.2, C6.2, C7.2, C8.2, C9.2, C10.2, C11.2, C12.2, C13.2, C14.2, C15.2, C16.2, C17.2, CR2032.2, D1.2, D3.2, D4.2, D5.2, D6.2, D7.2, D8.2, D9.2, D10.2, GPIO_CONTROLLER1.19, GPIO_CONTROLLER1.39, GPIO_CONTROLLER1.41, J3.2, J8.2, J9.3, J12.1, J15.1, J16.1, K1.A2, K2.A2, K3.A2, K4.A2, K5.A2, K6.A2, K7.A2, K8.A2, LED1.2, R8.1, R20.1, R21.1, SW1.C, TFT_CONTROLLER1.19, TFT_CONTROLLER1.39, TFT_CONTROLLER1.41, Term1.2, U1.4, U1.7, U2.10, U2.14, U2.22, U2.29, U3.5, U3.6, U3.7, U3.8, U3.9, U3.10, U3.11, U3.12, U3.13, U4.1, U5.2, U6.1, U7.2, U8.1
LIGHT1_PB7: GPIO_CONTROLLER1.35, R9.1
LIGHT2_PB6: GPIO_CONTROLLER1.34, R11.1
LIGHT3_PB5: GPIO_CONTROLLER1.33, R16.1
LIGHT4_PB4: GPIO_CONTROLLER1.32, R18.1
unnamed: BZ1.2, J12.2
unnamed: CR2032.1, U3.14
unnamed: D2.1, R8.2
unnamed: D3.1, K1.A1, Q1.3
unnamed: D4.1, K2.A1, Q2.3
unnamed: D5.1, K3.A1, Q3.3
unnamed: D6.1, K4.A1, Q4.3
unnamed: D7.1, K5.A1, Q6.3
unnamed: D8.1, K6.A1, Q7.3
unnamed: D9.1, K7.A1, Q8.3
unnamed: D10.1, K8.A1, Q9.3
unnamed: D11.1, R20.2
unnamed: D12.1, R21.2
unnamed: GPIO_CONTROLLER1.8, TFT_CONTROLLER1.9
unnamed: GPIO_CONTROLLER1.9, TFT_CONTROLLER1.8
unnamed: GPIO_CONTROLLER1.42, J8.1
unnamed: GPIO_CONTROLLER1.43, J8.3
unnamed: J1.1, U2.28
unnamed: J2.2, U2.27
unnamed: J3.1, TFT_CONTROLLER1.42
unnamed: J3.3, TFT_CONTROLLER1.43
unnamed: J4.1, K1.12
unnamed: J4.2, K1.11
unnamed: J4.3, K1.14
unnamed: J5.1, K2.12
unnamed: J5.2, K2.11
unnamed: J5.3, K2.14
unnamed: J6.1, K3.12
unnamed: J6.2, K3.11
unnamed: J6.3, K3.14
unnamed: J7.1, K4.12
unnamed: J7.2, K4.11
unnamed: J7.3, K4.14
unnamed: J10.1, K5.12
unnamed: J10.2, K5.11
unnamed: J10.3, K5.14
unnamed: J11.1, K6.12
unnamed: J11.2, K6.11
unnamed: J11.3, K6.14
unnamed: J13.1, K7.12
unnamed: J13.2, K7.11
unnamed: J13.3, K7.14
unnamed: J14.1, K8.12
unnamed: J14.2, K8.11
unnamed: J14.3, K8.14
unnamed: J15.2, SW3.2
unnamed: J16.2, SW2.2
unnamed: LED1.3, Q5.3, R15.1
unnamed: Q1.1, R9.2
unnamed: Q2.1, R10.2
unnamed: Q3.1, R11.2
unnamed: Q4.1, R12.2
unnamed: Q5.1, R14.1
unnamed: Q6.1, R16.2
unnamed: Q7.1, R17.2
unnamed: Q8.1, R18.2
unnamed: Q9.1, R19.2
RELAY1_PB15: GPIO_CONTROLLER1.24, R10.1
RELAY2_PB14: GPIO_CONTROLLER1.23, R12.1
RELAY3_PB13: GPIO_CONTROLLER1.22, R17.1
RELAY4_PB12: GPIO_CONTROLLER1.21, R19.1
TFT_CS_PB12: D1.3, TFT_CONTROLLER1.21
TFT_DC_PB14: D1.5, TFT_CONTROLLER1.23
TFT_MISO_PA6: D1.9, TFT_CONTROLLER1.12
TFT_MOSI_PA7: D1.6, TFT_CONTROLLER1.13
TFT_RST_PB13: D1.4, TFT_CONTROLLER1.22
TFT_SCK_PA5: D1.7, TFT_CONTROLLER1.11
T_TFT_CS_PB10: D1.11, TFT_CONTROLLER1.17
T_TFT_IRQ_PA9: D1.14, TFT_CONTROLLER1.26
T_TFT_MISO_PB4: D1.13, TFT_CONTROLLER1.32
T_TFT_MOSI_PB5: D1.12, TFT_CONTROLLER1.33
T_TFT_SCK_PB3: D1.10, TFT_CONTROLLER1.31
USER_LED_PA10: D2.2, GPIO_CONTROLLER1.27
WS2812b_PA9: GPIO_CONTROLLER1.26, Q5.2, R13.1
nRF24_CE_PB1: TFT_CONTROLLER1.15, U4.3
nRF24_CSN_PA11: TFT_CONTROLLER1.28, U4.4
nRF24_IRQ_PB2: TFT_CONTROLLER1.16, U4.8
nRF24_MISO_PA12: TFT_CONTROLLER1.29, U4.7
nRF24_MOSI_PA10: TFT_CONTROLLER1.27, U4.6
nRF24_SCK_PB0: TFT_CONTROLLER1.14, U4.5

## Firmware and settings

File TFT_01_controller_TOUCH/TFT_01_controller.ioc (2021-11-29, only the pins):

Mcu.UserName=STM32F411CEUx
PA2.Signal=USART2_TX
PA3.Signal=USART2_RX
PA5.Signal=SPI1_SCK
PA6.Signal=SPI1_MISO
PA7.Signal=SPI1_MOSI
PA8.GPIO_Label=TOUCH_IRQ
PA8.Signal=GPXTI8
PB10.GPIO_Label=TOUCH_CS
PB10.Signal=GPIO_Output
PB12.GPIO_Label=TFT_CS
PB12.Signal=GPIO_Output
PB13.GPIO_Label=TFT_RST
PB13.Signal=GPIO_Output
PB14.GPIO_Label=TFT_DC
PB14.Signal=GPIO_Output
PB3.Signal=SPI3_SCK
PB4.Signal=SPI3_MISO
PB5.Signal=SPI3_MOSI
PC13-ANTI_TAMP.GPIO_Label=BP_USER_LED
PC13-ANTI_TAMP.Signal=GPIO_Output
PC14-OSC32_IN.Signal=RCC_OSC32_IN
PC15-OSC32_OUT.Signal=RCC_OSC32_OUT

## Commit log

2021-07-20 Dodana obsługa i2c w CubeMX
2021-07-20 Czyta temperature i wilgotnosc zapisuje je do zmiennych Temp i Pressure, trzeba zrobić to w obsłudze przerwania
2021-09-06 Pomiar ciśnienia i temperatury przeniesiony do funkcji obsługi przerwania
2021-09-15 porzucona wersja ze względu na problem z targetem
    [main.c]
2021-09-15 Przeimportowany projekt z wersji 02 - działa pomiar temp i pressure w while
2021-10-14 Dodane UartIrqHandler i DmaReceiveIrqHandler do _it.c
2021-11-03 Dodane parsowanie do komendy podaj temperature
2021-11-03 Dziala juz odpowiedz na zapytanie dotyczace temperatury i cisnienia
2021-11-03 Dodana obsluga przekaznikow na polecenia z UARTA
2021-11-03 Migracja do nowej wersji Cube i dodanie kosci do uarta i parsowania
2021-11-25 Dziala parsowanie temperatury od drugiego uC i wyswietlanie
2021-11-29 Dodany plik z prototypem maszyny stanow do obslugi menuTFT
2021-11-30 Dziala przelaczanie pomiedzy parametrami a swiatlami i switchami
2021-12-03 Dodano definy z polozeniem, wymiarami i kolorami przyciskow od switchow i swiatel
2021-12-13 Zmiana trybu pracy RTC na fast mode i zmiana komunikacji z RTC na I2C po DMA
2021-12-13 Dodane parsowanie i wyswietlanie temperatury wewnatrz z ds18b20
2021-12-17 Dodana prosta biblioteka do oblugi ds18b20 z uzyciem DMA
2021-12-18 Dodana bardziej zaawansowana biblioteka do obslugi ws2812b i parsowanie komend dot LED WS
2021-12-18 Dodany szzkielet funkcji do obslugi dotyku w panelu sterowania ledami
2021-12-21 Dodane I2C3 do obslugi EEPROMu, TOUCH_IRQ przeniesione z PA8 na PA9
2021-12-22 Dodane czytanie i zapisywanie ilosci led do pamieci EEPROM
2021-12-23 Dodano UART6 do komunikacji z czujnikiem odległości
2021-12-29 Dodane dwa rozwiazania naprawienia problemu odswiezania uarta do sprawdzenia
    [main.c]
2022-01-05 Added device view in v0.1
2022-01-06 Dodana obsługa błędów w Error_Handler(), poprawione komentarze
    [main.c]
2022-01-07 Dodany plik z schematem Układu
    [free_michelle_v1_0.kicad_pcb, free_michelle_v1_0.kicad_sch]
2022-01-09 Dodany nowy schemat, naprawiony blad z symbolem f411
    [free_michelle_v1_0.kicad_pcb, free_michelle_v1_0.sch]
2022-01-09 Dodane 2 STM32F411 i polaczenie ich po UART
2022-01-09 Dodano polaczenia pomiedzy uC a TFT
    [free_michelle_v1_0.sch]
2022-01-09 Dodany DS3231 i podłączony
    [free_michelle_v1_0.sch]
2022-01-09 Dodane zapomniane rezystory podciągające dla SCL i SDA
    [free_michelle_v1_0.sch]
2022-01-10 Dodany do schematu element EEPROM 24AA01
    [free_michelle_v1_0.kicad_sch, free_michelle_v1_0.sch]
2022-01-10 Dodany L7805
    [free_michelle_v1_0.sch]
2022-01-10 Dodany LD1117V33
    [free_michelle_v1_0.sch]
2022-01-10 Dodane zasialnie i zlacza do programwoania
    [free_michelle_v1_0.sch]
2022-01-10 Dodane WS2812b
    [free_michelle_v1_0.sch]
2022-01-10 Poprawione zapomniane polaczenie led WS do uC
    [free_michelle_v1_0.sch]
2022-01-11 Dodane przekazniki z tranzystorami kluczującymi
    [free_michelle_v1_0.sch]
2022-01-11 Dodao i podlaczona nRF24
    [free_michelle_v1_0.sch]
2022-01-11 Dodane opisy i podział bloków na schemacie
    [free_michelle_v1_0.sch]
2022-01-12 Dosane ESP do schematu
    [free_michelle_v1_0.sch]
2022-01-12 Dosane przelaczniki wlaczania zasilania i zlacza do schematu
    [free_michelle_v1_0.sch]
2022-01-13 Dodany Buzzer
    [free_michelle_v1_0.sch]
2022-01-13 Poprzypisywane footprinty do glownych urzadzen
    [free_michelle_v1_0.sch]
2022-01-13 Powybierane wszystkie obudowy i poprzypisywane footprinty
    [free_michelle_v1_0.sch]
2022-01-14 Ulozone wstepnie elementy na PCB
    [Wykaz_elementów.xlsx, free_michelle_v1_0.sch]
2022-01-14 Zmienione zlacze dla WS2812b i dodany rezystor filtrujący napięcie
    [free_michelle_v1_0.kicad_pcb]
2022-01-15 Poprawki po rozmowie z Mackiem umieszczone na schemacie
    [free_michelle_v1_0.kicad_pcb, free_michelle_v1_0.sch]
2022-01-15 Wykonane polaczenia dla TFT uC i zasilanie
    [free_michelle_v1_0.kicad_pcb]
2022-01-15 Wylano pola masy na obu stronach PCB
    [free_michelle_v1_0.kicad_pcb]
2022-01-15 Dodane napisy i otwory montarzowe pod TFT
    [free_michelle_v1_0.kicad_pcb]
2022-01-18 Gotowa płytka przed generacją gerberow
    [Wykaz_elementów.xlsx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]
2022-01-18 Dodane gerbery dla jlc
    [free_michelle_v1_0-B_Cu.gbl, free_michelle_v1_0-B_Mask.gbs, free_michelle_v1_0-B_Paste.gbp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]
2022-01-18 Poprawione warstwy z napisami
    [free_michelle_v1_0-B_Cu.gbl, free_michelle_v1_0-B_Mask.gbs, free_michelle_v1_0-B_Paste.gbp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]
2022-01-18 Wygenerowane gerbery dla jlcpcb z poprawionymi warstwami napisów
    [free_michelle_v1_0-B_Cu.gbl, free_michelle_v1_0-B_Mask.gbs, free_michelle_v1_0-B_Paste.gbp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]
